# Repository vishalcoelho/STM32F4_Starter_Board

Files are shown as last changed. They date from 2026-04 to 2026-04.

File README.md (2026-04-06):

# STM32F4_Starter_Board
KiCAD 9 project for the STM32F405RGT6 starter board

---

I have been following [Phil's Lab Tutorial](https://www.youtube.com/watch?v=C7-8nUU6e3E) on designing your first PCB in KiCad and using JLCPCB as the assembly house. I did the entire project in KiCAD 9, which differs slightly from the video, and ended up taking notes :memo: and screenshots :camera: along the way, which I put into a four part blog:

1. :triangular_ruler: [First STM32 PCB Design in KiCad and JLCPCB Assembly: Part I - Schematic Layout](https://vishalcoelho.github.io/blog/kicad/pcb-design/kicad-stm32-usb-pcb-design-jlcpcb-assy-part-1/)
2. :world_map: [First STM32 PCB Design in KiCad and JLCPCB Assembly: Part II - Board Layout](https://vishalcoelho.github.io/blog/kicad/pcb-design/kicad-stm32-usb-pcb-design-jlcpcb-assy-part-2/)
3. :traffic_light: [First STM32 PCB Design in KiCad and JLCPCB Assembly: Part III - Routing](https://vishalcoelho.github.io/blog/kicad/pcb-design/kicad-stm32-usb-pcb-design-jlcpcb-assy-part-3/)
4. :factory: [First STM32 PCB Design in KiCad and JLCPCB Assembly: Part IV - Manufacturing and Assembly](https://vishalcoelho.github.io/blog/kicad/pcb-design/kicad-stm32-usb-pcb-design-jlcpcb-assy-part-4/)

> :pray: Apologies if the blog doesn't read like a normal tutorial, they really were notes I took for later reference.

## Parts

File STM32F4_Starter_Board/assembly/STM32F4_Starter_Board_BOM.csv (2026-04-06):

Comment | Designator | Footprint | JLCPCB Part # (optional)
2u2 | C1,C2 | Capacitor_SMD:C_0603_1608Metric | C23630
4u7 | C3,C17 | Capacitor_SMD:C_0603_1608Metric | C19666
100n | C4,C5,C6,C7,C8 | Capacitor_SMD:C_0402_1005Metric | C1525
1u | C9 | Capacitor_SMD:C_0402_1005Metric | C52923
10n | C10 | Capacitor_SMD:C_0603_1608Metric | C57112
12p | C11,C12 | Capacitor_SMD:C_0402_1005Metric | C1547
10u | C13,C15,C16 | Diode_SMD:D_1206_3216Metric | C13585
10n | C14 | Diode_SMD:D_1206_3216Metric | C1846
YELLOW | D1 | LED_SMD:LED_0603_1608Metric | C2290
B5819W | D2,D3 | Diode_SMD:D_SOD-123 | C8598
RED | D5 | LED_SMD:LED_0603_1608Metric | C2286
250mA | F1 | Fuse:Fuse_1206_3216Metric | C83557
600 @ 100MHz | FB1 | Inductor_SMD:L_0805_2012Metric | C1017
Screw_Terminal_01x02 | J1 | TerminalBlock_Phoenix:TerminalBlock_Phoenix_PT-1,5-2-3.5-H_1x02_P3.50mm_Horizontal | C415432
SWD | J2 | Connector_PinHeader_1.27mm:PinHeader_2x05_P1.27mm_Vertical_SMD | C4943297
I2C | J3 | Connector_Molex:Molex_PicoBlade_53048-0410_1x04_P1.25mm_Horizontal | C588275
USART | J4 | Connector_Molex:Molex_PicoBlade_53048-0410_1x04_P1.25mm_Horizontal | C588275
USB_B_Micro | J5 | Connector_USB:USB_Micro-B_Molex_47346-0001 | C132560
39n | L1 | Inductor_SMD:L_0402_1005Metric | C26443
10u | L2 | Inductor_SMD:L_Sunlord_MWSA0518S | C408349
AO3401A | Q1 | Package_TO_SOT_SMD:SOT-23 | C15127
10K | R1 | Resistor_SMD:R_0402_1005Metric | C25744
47 | R2 | Resistor_SMD:R_0402_1005Metric | C23182
1k5 | R3 | Resistor_SMD:R_0603_1608Metric | C22843
100K | R4 | Resistor_SMD:R_0603_1608Metric | C25803
68K | R5 | Resistor_SMD:R_0603_1608Metric | C177284
47K | R6 | Resistor_SMD:R_0603_1608Metric | C25819
15K | R7 | Resistor_SMD:R_0603_1608Metric | C22809
270 | R8 | Resistor_SMD:R_0603_1608Metric | C22966
22 | R9,R10,R11,R12,R15,R16,R17,R18 | Resistor_SMD:R_0402_1005Metric | C23345
2k2 | R13,R14 | Resistor_SMD:R_0603_1608Metric | C4190
1K | R19 | Resistor_SMD:R_0603_1608Metric | C21190
SW_SPDT | SW1 | Button_Switch_SMD:SW_SPDT_PCM12 | C221841
STM32F405RGT6 | U1 | Package_QFP:LQFP-64_10x10mm_P0.5mm | C15742
MP2359BJ-LF-Z | U2 | Package_TO_SOT_SMD:SOT-23-6 | C14259
USBLC6-2SC6 | U3 | Package_TO_SOT_SMD:SOT-23-6 | C7519
16MHz | Y1 | Crystal:Crystal_SMD_3225-4Pin_3.2x2.5mm | C13738

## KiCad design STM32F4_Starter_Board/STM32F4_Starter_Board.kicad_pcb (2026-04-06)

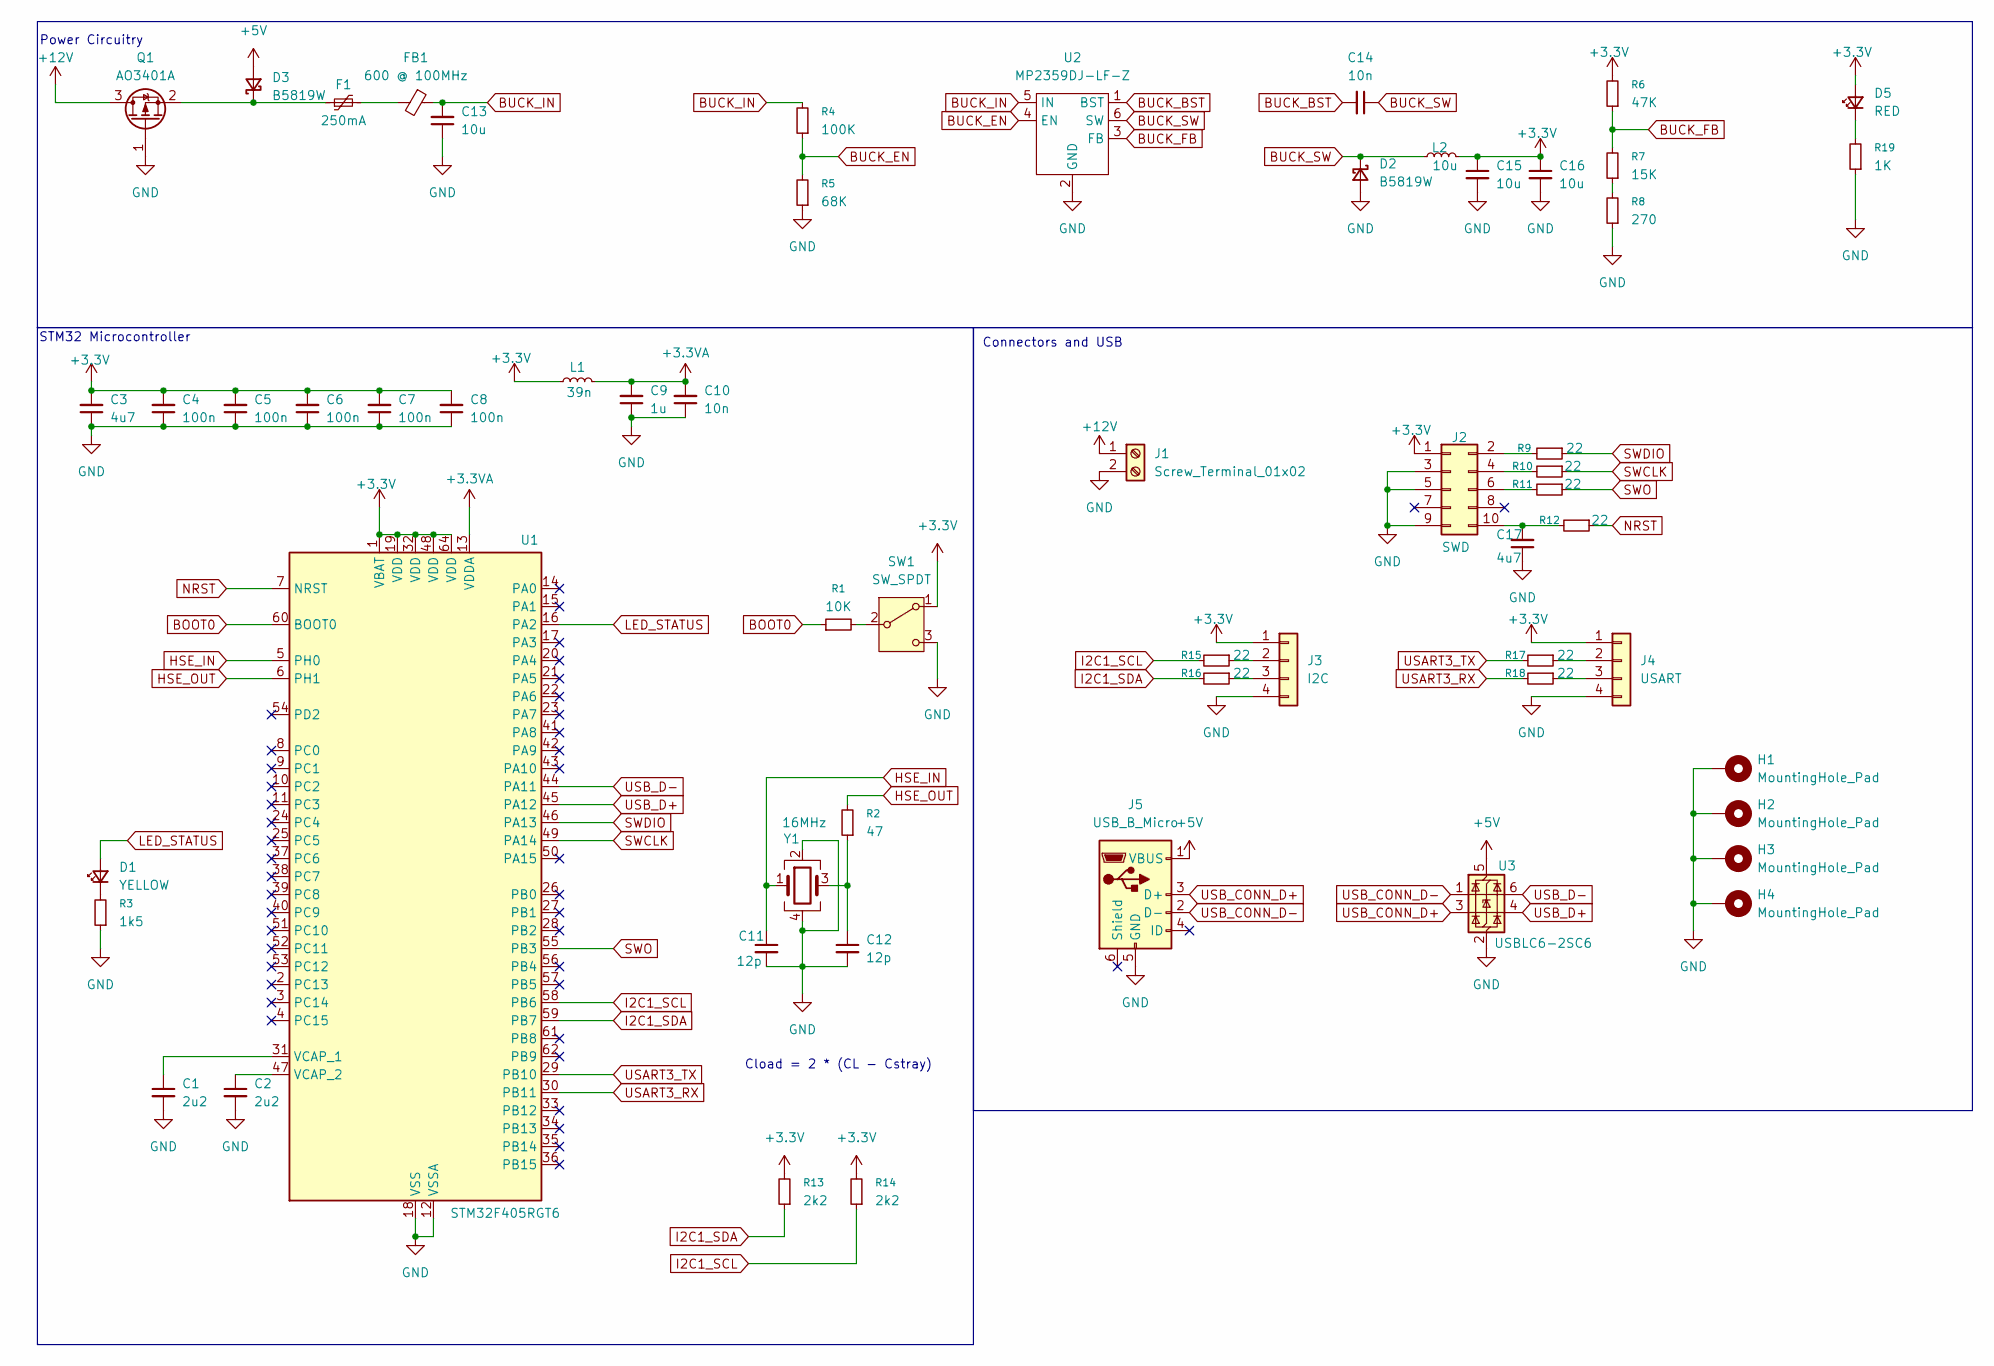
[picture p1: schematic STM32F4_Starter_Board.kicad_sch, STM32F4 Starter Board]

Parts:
C1, C2: 2u2; C_0603_1608Metric; JLCPCB Part # C23630
C3, C17: 4u7; C_0603_1608Metric; JLCPCB Part # C19666
C4, C5, C6, C7, C8: 100n; C_0402_1005Metric; JLCPCB Part # C1525
C9: 1u; C_0402_1005Metric; JLCPCB Part # C52923
C10: 10n; C_0603_1608Metric; JLCPCB Part # C57112
C11, C12: 12p; C_0402_1005Metric; JLCPCB Part # C1547
C13, C15, C16: 10u; D_1206_3216Metric; JLCPCB Part # C13585
C14: 10n; D_1206_3216Metric; JLCPCB Part # C1846
D1: YELLOW; LED_0603_1608Metric; JLCPCB Part # C2290
D2, D3: B5819W; D_SOD-123; JLCPCB Part # C8598
D5: RED; LED_0603_1608Metric; JLCPCB Part # C2286
F1: 250mA; Fuse_1206_3216Metric; JLCPCB Part # C83557
FB1: 600 @ 100MHz; L_0805_2012Metric; JLCPCB Part # C1017
H1, H2, H3, H4: MountingHole_Pad; MountingHole_4.3mm_M4_Pad_Via
J1: Screw_Terminal_01x02; TerminalBlock_Phoenix_PT-1,5-2-3.5-H_1x02_P3.50mm_Horizontal; JLCPCB Part # C415432
J2: SWD; PinHeader_2x05_P1.27mm_Vertical_SMD; JLCPCB Part # C4943297
J3: I2C; Molex_PicoBlade_53048-0410_1x04_P1.25mm_Horizontal; JLCPCB Part # C588275
J4: USART; Molex_PicoBlade_53048-0410_1x04_P1.25mm_Horizontal; JLCPCB Part # C588275
J5: USB_B_Micro; USB_Micro-B_Molex_47346-0001; JLCPCB Part # C132560
L1: 39n; L_0402_1005Metric; JLCPCB Part # C26443
L2: 10u; L_Sunlord_MWSA0518S; JLCPCB Part # C408349
Q1: AO3401A; SOT-23; JLCPCB Part # C15127
R1: 10K; R_0402_1005Metric; JLCPCB Part # C25744
R2: 47; R_0402_1005Metric; JLCPCB Part # C23182
R3: 1k5; R_0603_1608Metric; JLCPCB Part # C22843
R4: 100K; R_0603_1608Metric; JLCPCB Part # C25803
R5: 68K; R_0603_1608Metric; JLCPCB Part # C177284
R6: 47K; R_0603_1608Metric; JLCPCB Part # C25819
R7: 15K; R_0603_1608Metric; JLCPCB Part # C22809
R8: 270; R_0603_1608Metric; JLCPCB Part # C22966
R9, R10, R11, R12, R15, R16, R17, R18: 22; R_0402_1005Metric; JLCPCB Part # C23345
R13, R14: 2k2; R_0603_1608Metric; JLCPCB Part # C4190
R19: 1K; R_0603_1608Metric; JLCPCB Part # C21190
SW1: SW_SPDT; SW_SPDT_PCM12; JLCPCB Part # C221841
U1: STM32F405RGT6; LQFP-64_10x10mm_P0.5mm; JLCPCB Part # C15742
U2: MP2359BJ-LF-Z; SOT-23-6; JLCPCB Part # C14259
U3: USBLC6-2SC6; SOT-23-6; JLCPCB Part # C7519
Y1: 16MHz; Crystal_SMD_3225-4Pin_3.2x2.5mm; JLCPCB Part # C13738

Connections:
+3.3V: C3.2, C4.2, C5.2, C6.2, C7.2, C8.2, C15.1, C16.1, D5.2 (A), J2.1, J3.1, J4.1, L1.1, L2.2, R6.2, R13.2, R14.2, SW1.1 (A), U1.1 (VBAT), U1.19 (VDD), U1.32 (VDD), U1.48 (VDD), U1.64 (VDD)
+3.3VA: C9.2, C10.2, L1.2, U1.13 (VDDA)
+5V: D3.2 (A), J5.1 (VBUS), U3.5 (VBUS)
+12V: J1.1, Q1.3 (D)
BOOT0: R1.1, U1.60 (BOOT0)
BUCK_BST: C14.2, U2.1 (BST)
BUCK_EN: R4.1, R5.2, U2.4 (EN)
BUCK_FB: R6.1, R7.2, U2.3 (FB)
BUCK_IN: C13.2, FB1.1, R4.2, U2.5 (IN)
BUCK_SW: C14.1, D2.1 (K), L2.1, U2.6 (SW)
GND: C1.2, C2.2, C3.1, C4.1, C5.1, C6.1, C7.1, C8.1, C9.1, C10.1, C11.2, C12.2, C13.1, C15.2, C16.2, C17.1, D2.2 (A), H1.1, H2.1, H3.1, H4.1, J1.2, J2.3, J2.5, J2.9, J3.4, J4.4, J5.5 (GND), Q1.1 (G), R3.1, R5.1, R8.1, R19.1, SW1.3 (C), U1.12 (VSSA), U1.18 (VSS), U1.63 (VSS), U2.2 (GND), U3.2 (GND), Y1.2, Y1.4
HSE_IN: C11.1, U1.5 (PH0), Y1.1
HSE_OUT: R2.2, U1.6 (PH1)
I2C1_SCL: R14.1, R15.2, U1.58 (PB6)
I2C1_SDA: R13.1, R16.2, U1.59 (PB7)
LED_STATUS: D1.2 (A), U1.16 (PA2)
NRST: R12.1, U1.7 (NRST)
unnamed: C12.1, R2.1, Y1.3
unnamed: D1.1 (K), R3.2
unnamed: D3.1 (K), F1.1, Q1.2 (S)
unnamed: D5.1 (K), R19.2
unnamed: F1.2, FB1.2
unnamed: J2.2, R9.2
unnamed: J2.4, R10.2
unnamed: J2.6, R11.2
unnamed: C17.2, J2.10, R12.2
unnamed: J3.2, R15.1
unnamed: J3.3, R16.1
unnamed: J4.2, R17.1
unnamed: J4.3, R18.1
unnamed: R7.1, R8.2
unnamed: R1.2, SW1.2 (B)
unnamed: C1.1, U1.31 (VCAP_1)
unnamed: C2.1, U1.47 (VCAP_2)
SWCLK: R10.1, U1.49 (PA14)
SWDIO: R9.1, U1.46 (PA13)
SWO: R11.1, U1.55 (PB3)
USART3_RX: R18.2, U1.30 (PB11)
USART3_TX: R17.2, U1.29 (PB10)
USB_CONN_D+: J5.3 (D+), U3.3 (I/O2)
USB_CONN_D-: J5.2 (D-), U3.1 (I/O1)
USB_D+: U1.45 (PA12), U3.4 (I/O2)
USB_D-: U1.44 (PA11), U3.6 (I/O1)

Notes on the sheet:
Cload = 2 * (CL - Cstray)
STM32 Microcontroller
Power Circuitry
Connectors and USB

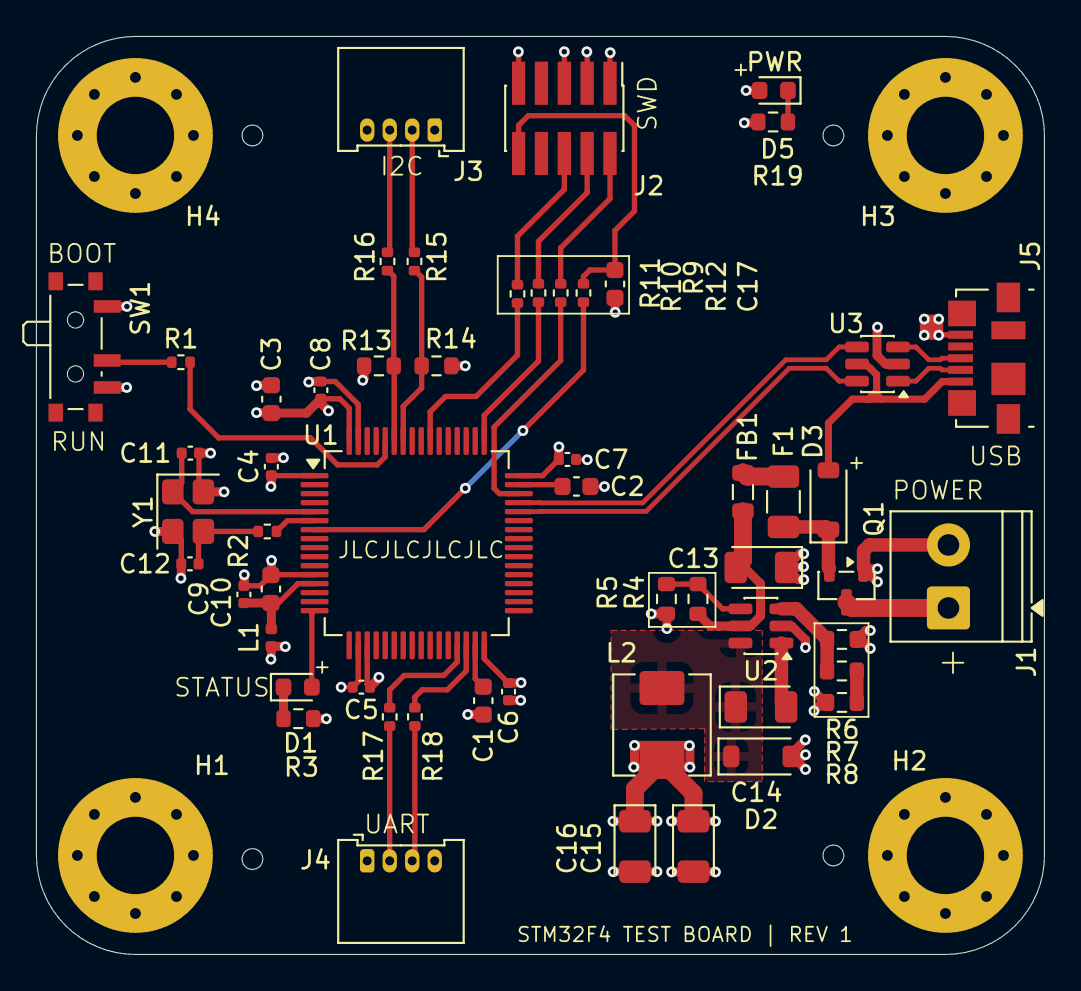
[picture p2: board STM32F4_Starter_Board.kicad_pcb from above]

Board: 4 copper layers, 56.0 x 51.0 mm, 59 parts (0 on the bottom side), 43 nets.

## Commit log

2026-04-06 [KiCAD] Add the KiCAD 9 project files for the STM32F4 Starter Board.
    [STM32F4_Starter_Board-B_Cu.gbr, STM32F4_Starter_Board-B_Mask.gbr, STM32F4_Starter_Board-B_Paste.gbr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]
2026-04-06 [KICAD] Force add the asesembly files.
    [STM32F4_Starter_Board-Footprint_Positions.csv, STM32F4_Starter_Board_BOM.csv]
